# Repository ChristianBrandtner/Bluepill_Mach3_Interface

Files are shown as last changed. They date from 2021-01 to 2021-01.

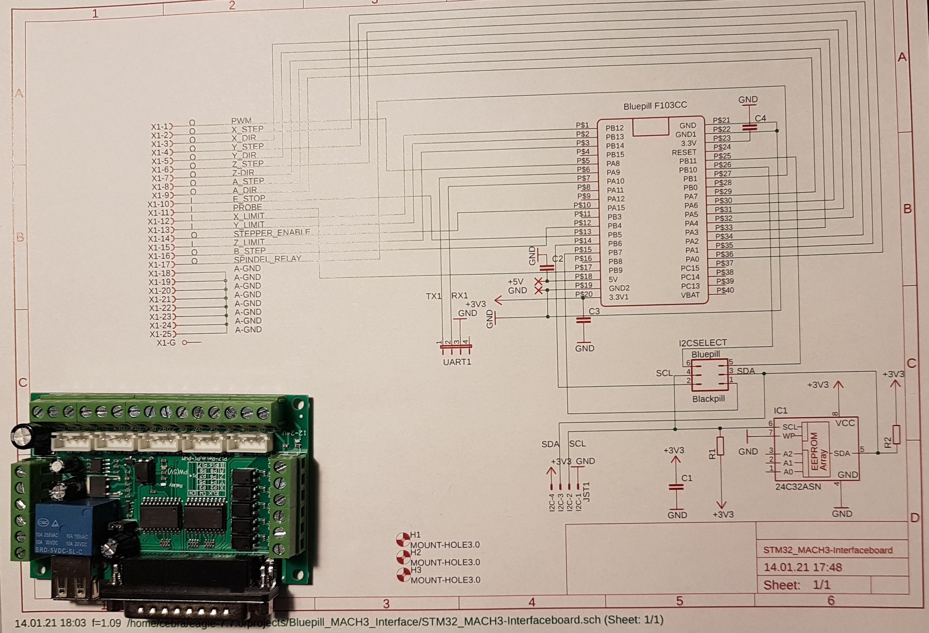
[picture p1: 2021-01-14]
Mach3InterfaceBoard.jpg

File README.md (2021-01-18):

# Bluepill_Mach3_Interface
Adapterboard to use cheap (7€) Mach3 CNC Breakout Board with Bluepill/Blackpill
You can find it at Aliexpress, search for  "MACH3 Engraving machine 5 Axis CNC Breakout Board With Optical Coupler" or similar.

I want to use it with 3 Axis millingmachine and grblHAL. https://github.com/terjeio/grblHAL

This is not tested, PCB is ordered
14.01.2021

new version V2, because 5V supply for MACH3 Interfaceboard are necessary.
Powersupply is now 12-24V for Bluepill_Mach3 Interface and MACH3 Interfaceboard.

18.01.2021

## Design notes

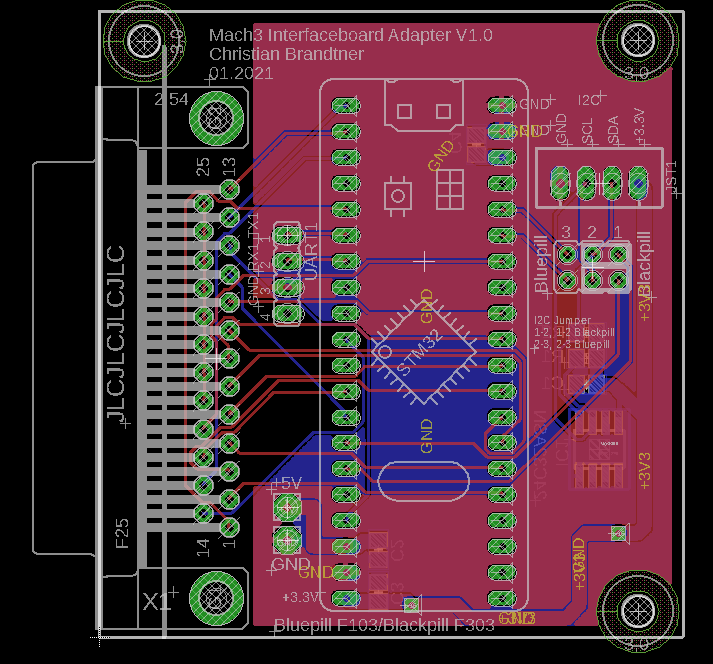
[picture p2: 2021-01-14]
Board.png

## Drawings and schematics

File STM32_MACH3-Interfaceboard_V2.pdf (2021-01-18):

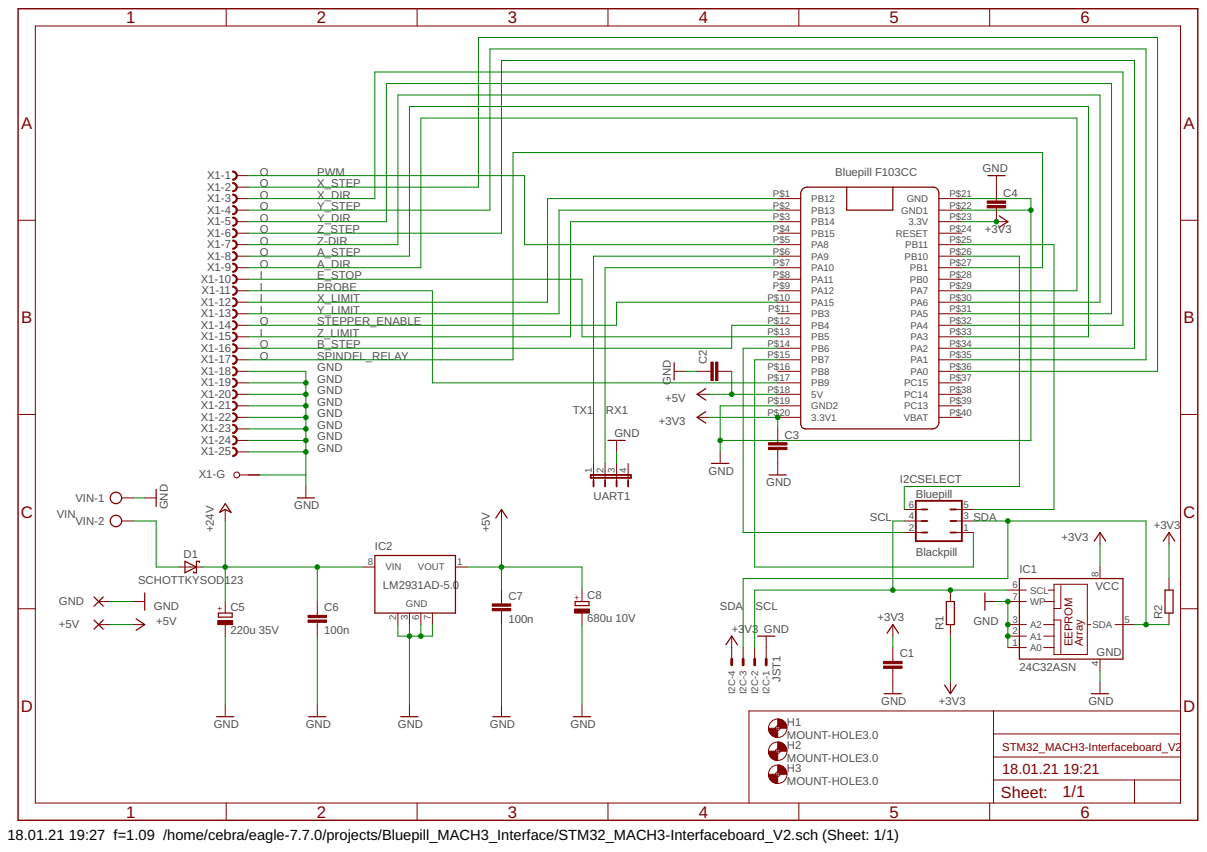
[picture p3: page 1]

H1 MOUNT-HOLE3.0 H2 MOUNT-HOLE3.0 H3 MOUNT-HOLE3.0

Sheet: 1/1

18.01.21 19:27 f=1.09 /home/cebra/eagle-7.7.0/projects/Bluepill_MACH3_Interface/STM32_MACH3-Interfaceboard_V2.sch (Sheet: 1/1)

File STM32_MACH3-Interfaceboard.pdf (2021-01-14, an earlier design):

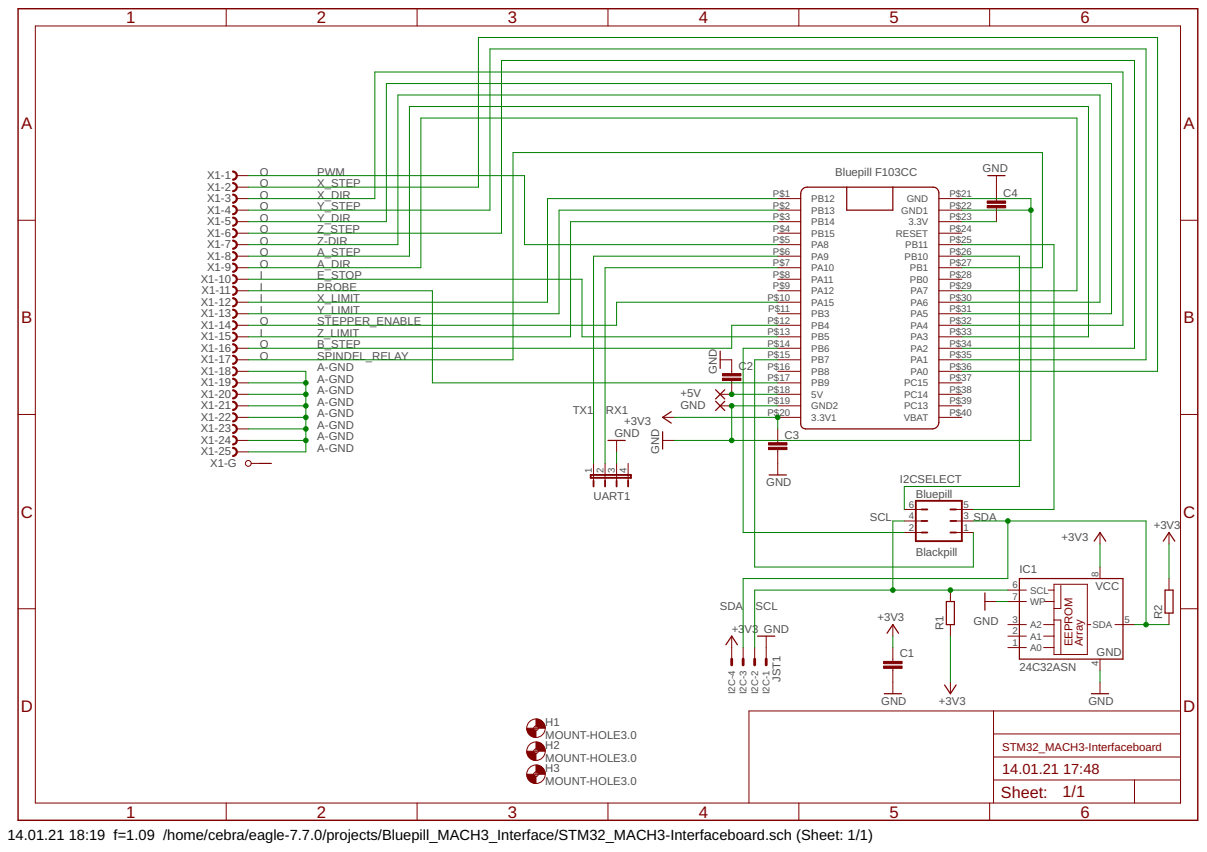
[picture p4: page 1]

P$18
GND2 P$19

14.01.21 18:19 f=1.09 /home/cebra/eagle-7.7.0/projects/Bluepill_MACH3_Interface/STM32_MACH3-Interfaceboard.sch (Sheet: 1/1)

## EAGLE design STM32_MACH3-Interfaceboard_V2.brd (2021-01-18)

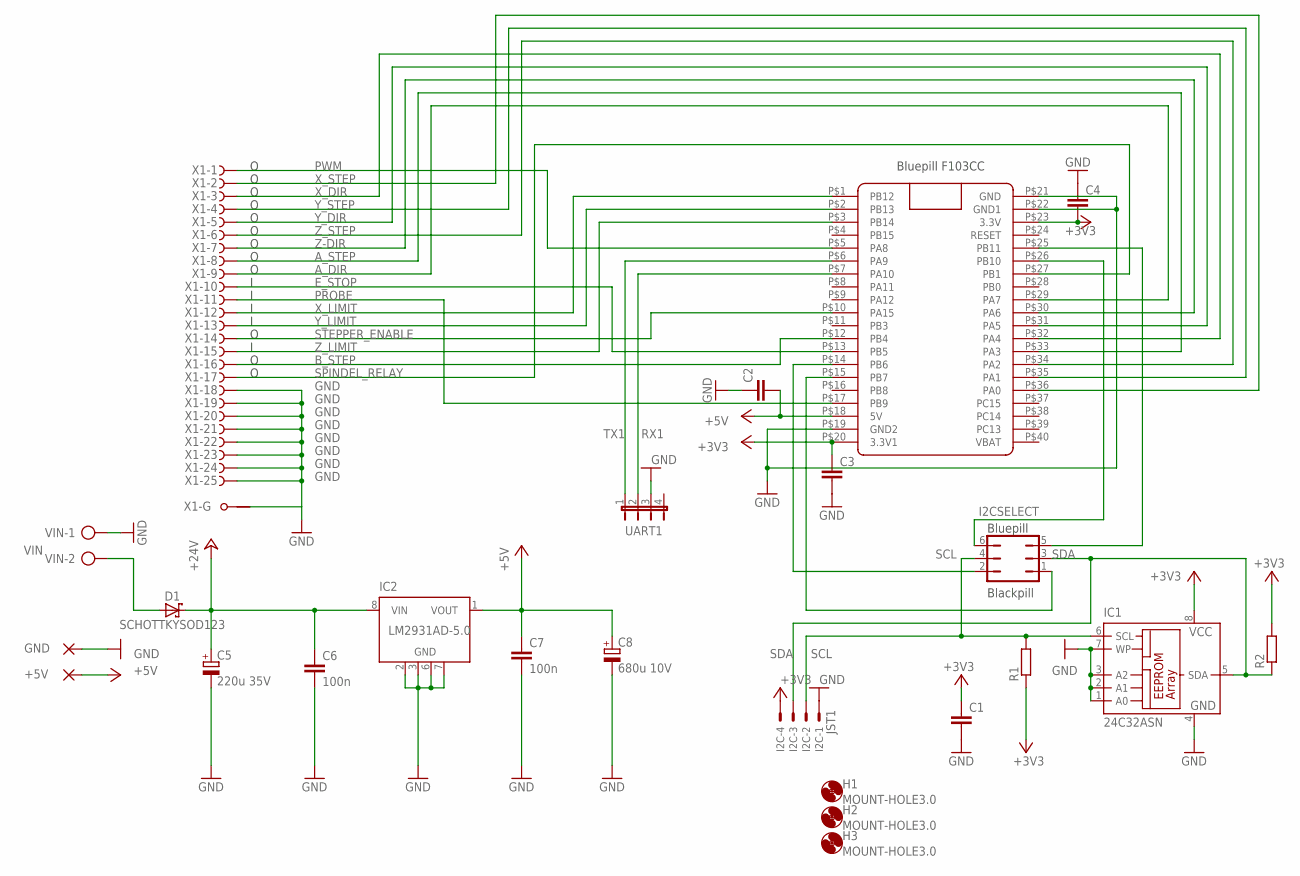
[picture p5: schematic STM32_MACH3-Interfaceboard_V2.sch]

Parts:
+5V: 2,54/1,0
C1, C2, C3, C4: C-EUC0805; C0805
C5: 220u 35V; PANASONIC_E7
C6, C7: 100n; C0805
C8: 680u 10V; PANASONIC_E7
D1: SCHOTTKYSOD123; SOD123
GND: 2,54/1,0
H1, H2, H3: MOUNT-HOLE3.0; 3,0
I2C: JST1; JST-XH-04-PACKAGE-LONG-PAD
I2CSELECT: JP3Q
IC1: 24C32ASN; SO-08
IC2: LM2931AD-5.0; SOIC8
R1, R2: R-EU_R0805; R0805
U$1: BLUE_PILL
UART1: JP4E; JP4
VIN: AK500/2
X1: F25HPS; F25HP

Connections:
+3V3: C1.1, C3.1, C4.2, I2C.4, IC1.8 (VCC), R1.1, R2.2, U$1.P$20 (3.3V1), U$1.P$23 (3.3V)
+5V: +5V.1, C2.2, C7.1, C8.+, IC2.1 (VOUT), U$1.P$18 (5V)
+24V: C5.+, C6.1, D1.C, IC2.8 (VIN)
A_DIR: U$1.P$29 (PA7), X1.9 (F)
A_STEP: U$1.P$33 (PA3), X1.8 (F)
B_STEP: U$1.P$12 (PB4), X1.16 (F)
E_STOP: U$1.P$13 (PB5), X1.10 (F)
GND: C1.2, C2.1, C3.2, C4.1, C5.-, C6.2, C7.2, C8.-, GND.1, I2C.1, IC1.1 (A0), IC1.2 (A1), IC1.3 (A2), IC1.4 (GND), IC1.7 (WP), IC2.2 (GND), IC2.3 (GND), IC2.6 (GND), IC2.7 (GND), U$1.P$19 (GND2), U$1.P$21 (GND), U$1.P$22 (GND1), UART1.3, VIN.1, X1.18 (F), X1.19 (F), X1.20 (F), X1.21 (F), X1.22 (F), X1.23 (F), X1.24 (F), X1.25 (F), X1.G1
unnamed: I2CSELECT.5, U$1.P$25 (PB11)
unnamed: I2CSELECT.6, U$1.P$26 (PB10)
unnamed: I2CSELECT.2, U$1.P$14 (PB6)
unnamed: I2CSELECT.1, U$1.P$15 (PB7)
PROBE: U$1.P$17 (PB9), X1.11 (F)
PWM: U$1.P$5 (PA8), X1.1 (F)
RX1: U$1.P$7 (PA10), UART1.2
SCL: I2C.2, I2CSELECT.4, IC1.6 (SCL), R1.2
SDA: I2C.3, I2CSELECT.3, IC1.5 (SDA), R2.1
SPINDEL_RELAY: U$1.P$27 (PB1), X1.17 (F)
STEPPER_ENABLE: U$1.P$10 (PA15), X1.14 (F)
TX1: U$1.P$6 (PA9), UART1.1
VIN: D1.A, VIN.2
X_DIR: U$1.P$32 (PA4), X1.3 (F)
X_LIMIT: U$1.P$1 (PB12), X1.12 (F)
X_STEP: U$1.P$36 (PA0), X1.2 (F)
Y_DIR: U$1.P$31 (PA5), X1.5 (F)
Y_LIMIT: U$1.P$2 (PB13), X1.13 (F)
Y_STEP: U$1.P$35 (PA1), X1.4 (F)
Z-DIR: U$1.P$30 (PA6), X1.7 (F)
Z_LIMIT: U$1.P$3 (PB14), X1.15 (F)
Z_STEP: U$1.P$34 (PA2), X1.6 (F)

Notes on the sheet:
Bluepill F103CC
Bluepill
Blackpill

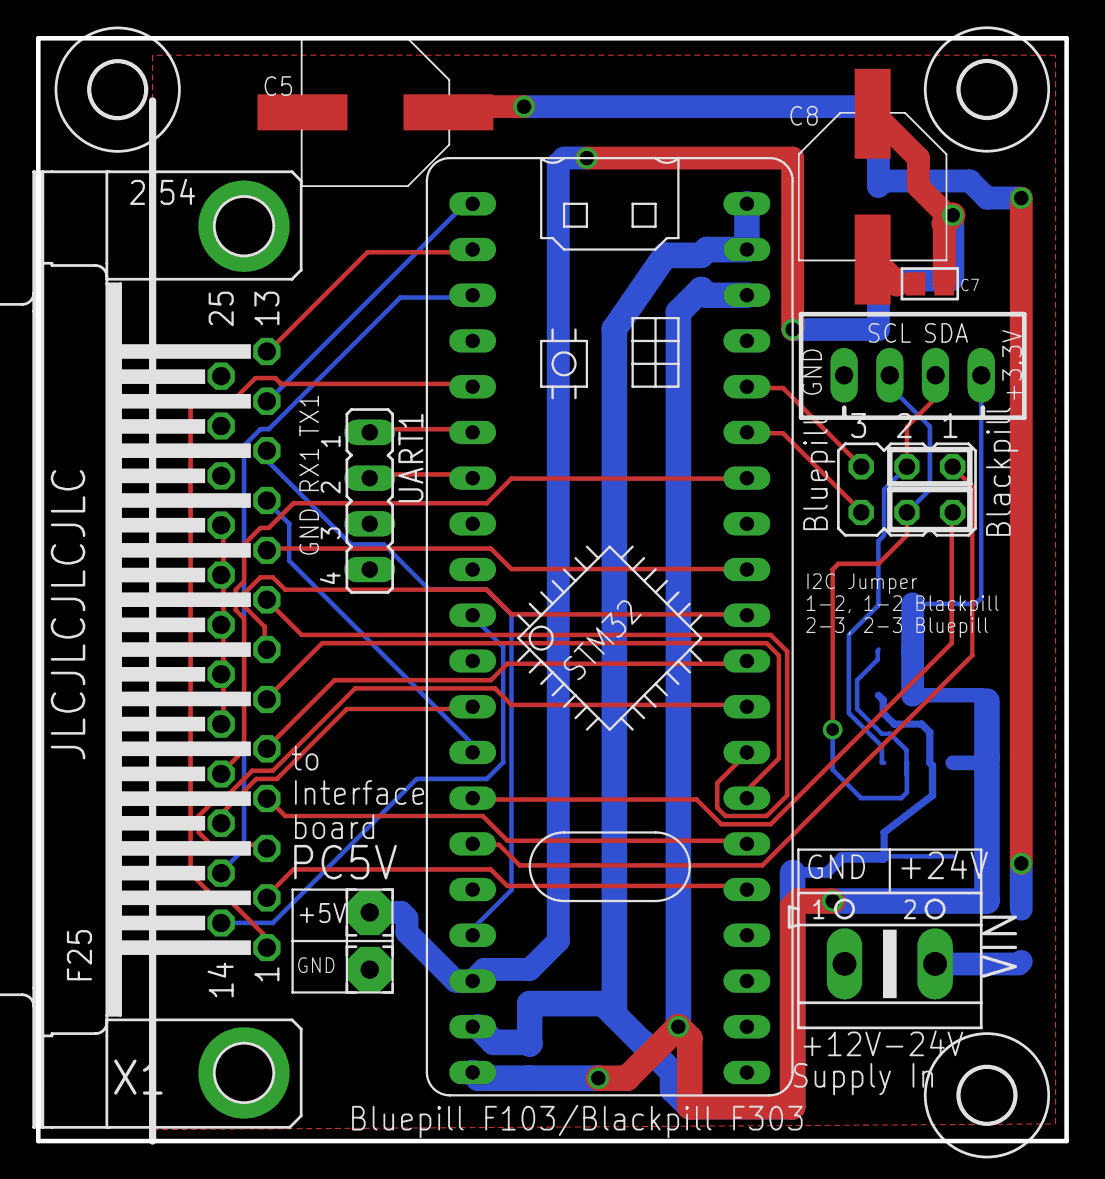
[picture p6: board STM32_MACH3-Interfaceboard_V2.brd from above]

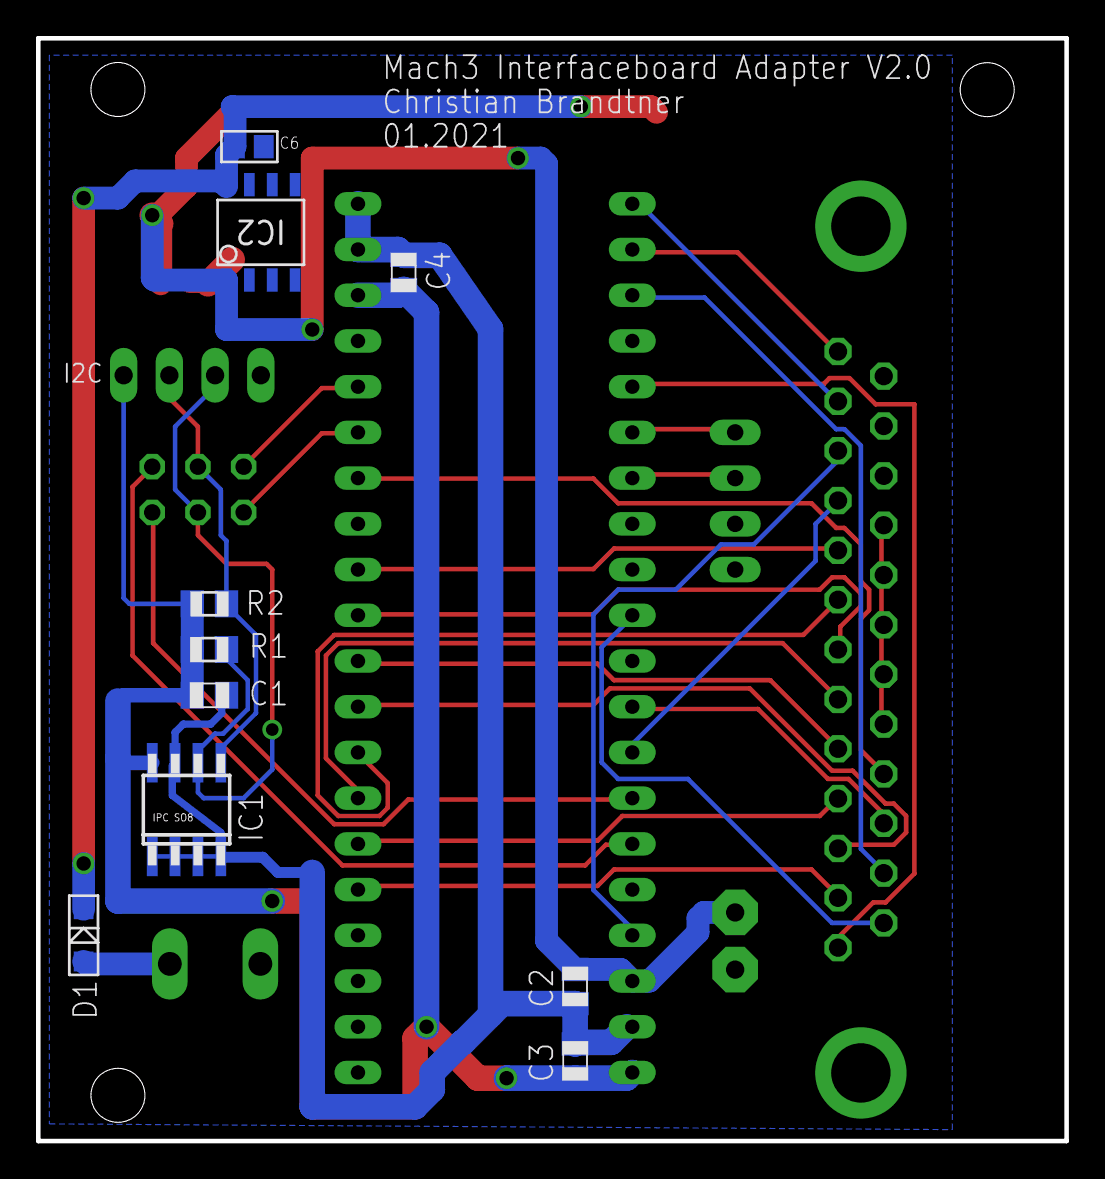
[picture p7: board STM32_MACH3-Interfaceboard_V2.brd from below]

Board: 2 copper layers, 57.1 x 61.3 mm, 24 parts (10 on the bottom side), 30 nets.
